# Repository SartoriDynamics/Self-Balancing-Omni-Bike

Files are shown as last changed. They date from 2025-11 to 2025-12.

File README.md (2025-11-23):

# Self-Balancing Omni Bicycle

UFMG BIAO-Kit is placed under the MIT License  
Copyright (c) 2024 by GTI (UFMG)

Hardware:
* ESP-WROOM-32 30 pin development board
* 2 Nidec 24-H
* 2 Set Tire wheel 88516 + 88517
* 1 2GT-280 belt, width 6mm
* 1 Module GY-521 MPU-6050
* 1 Power Bank Box Charger, DC 12V output, 3x18650 batteries

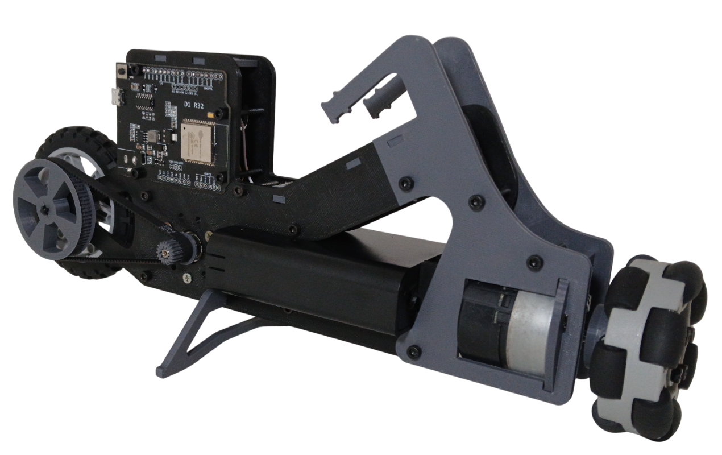
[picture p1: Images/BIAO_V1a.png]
BIAO

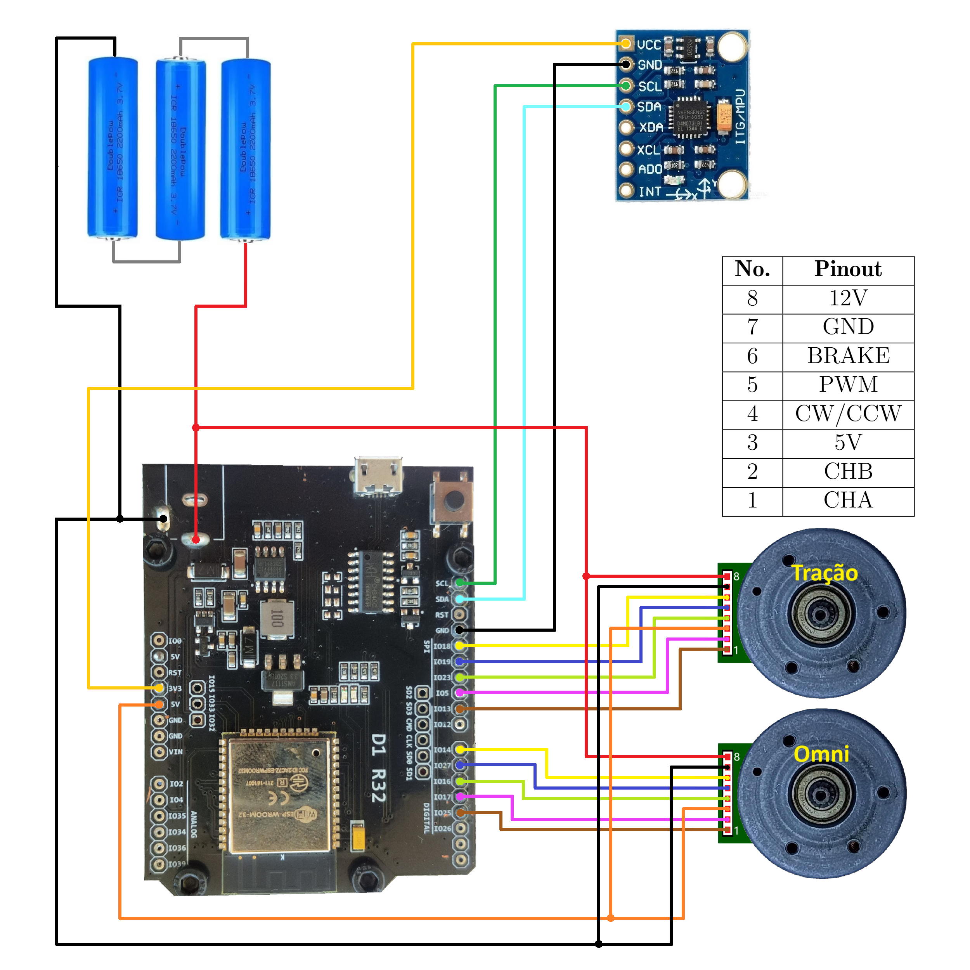
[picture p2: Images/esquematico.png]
esquematico


[Demonstration video](https://www.youtube.com/watch?v=WBLHfCbsgjU)

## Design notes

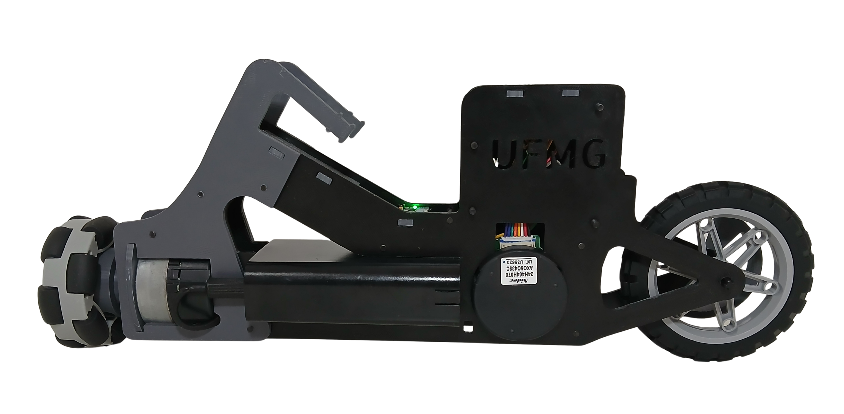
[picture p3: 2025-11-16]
Images/BIAO_V1b.png

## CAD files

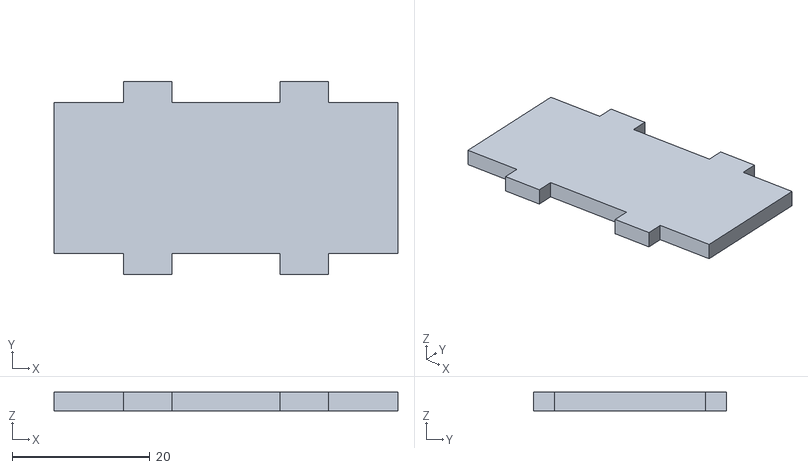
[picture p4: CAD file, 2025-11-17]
3D printing/Files/back_cover.stl
50.0 x 28.0 x 2.70

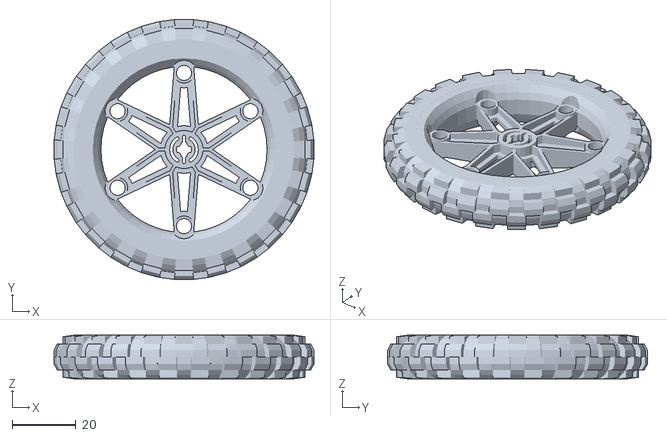
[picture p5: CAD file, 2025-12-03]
3D printing/Files/Extra/wheel.stl
81.5 x 81.5 x 13.7

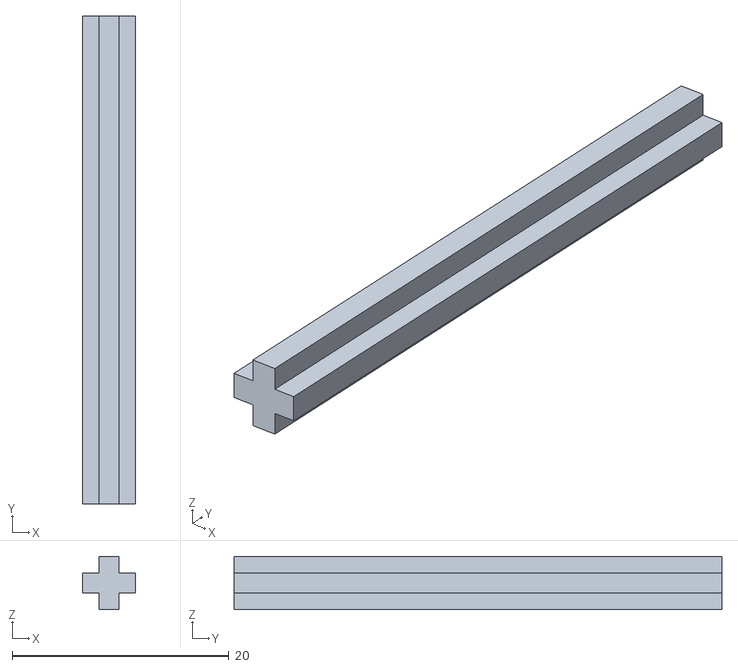
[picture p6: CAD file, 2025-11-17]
3D printing/Files/Extra/wheel_axle.stl
4.90 x 45.0 x 4.90

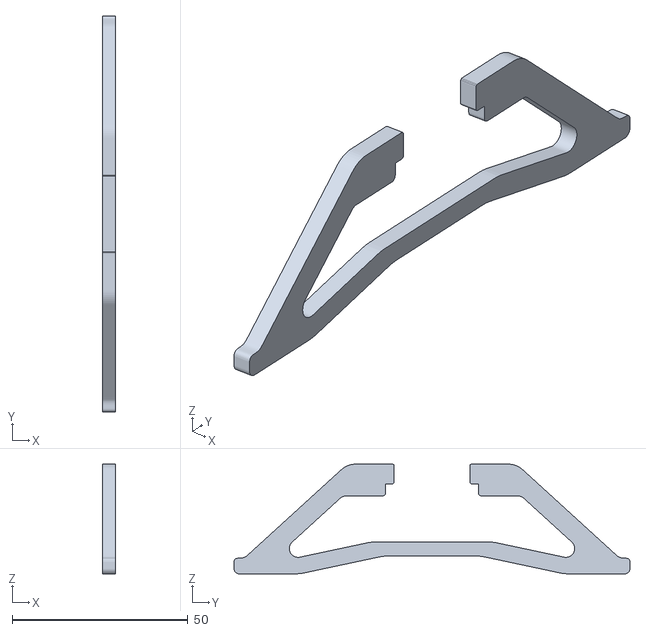
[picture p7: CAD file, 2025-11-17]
3D printing/Files/support.stl
3.60 x 112.7 x 31.2

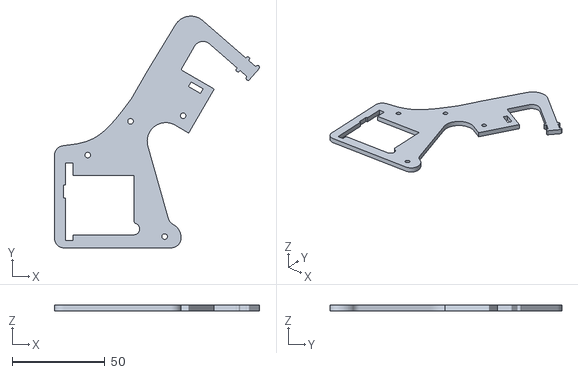
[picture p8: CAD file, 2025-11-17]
3D printing/Files/left_fork.stl
110.8 x 125.2 x 3.00

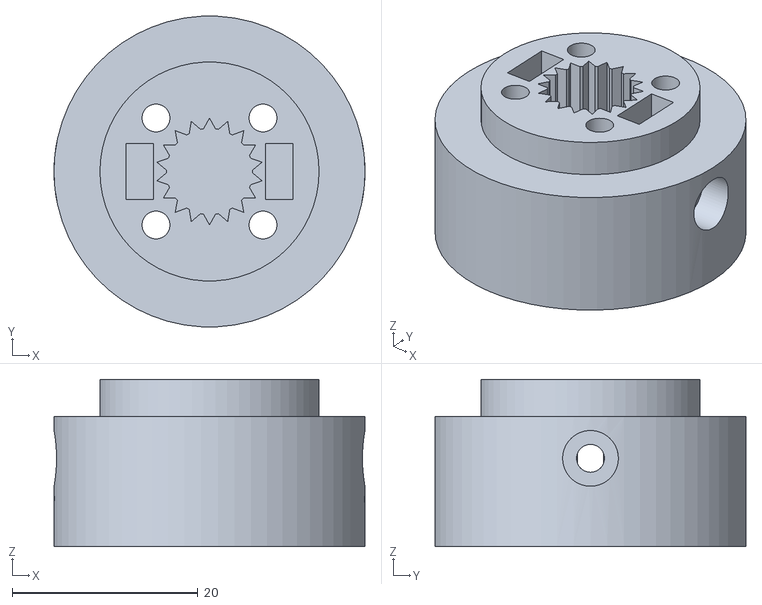
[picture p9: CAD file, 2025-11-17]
3D printing/Files/Omni_holder.stl
33.5 x 33.5 x 18.0

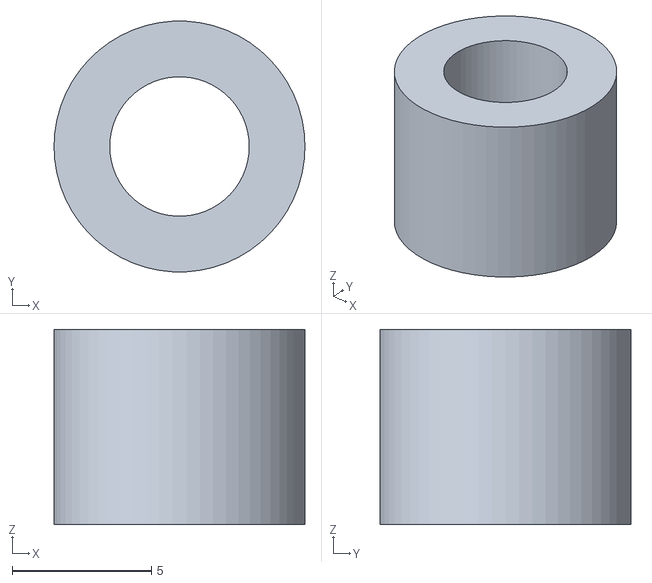
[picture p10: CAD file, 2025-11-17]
3D printing/Files/wheel_spacer.stl
9.00 x 8.99 x 7.00

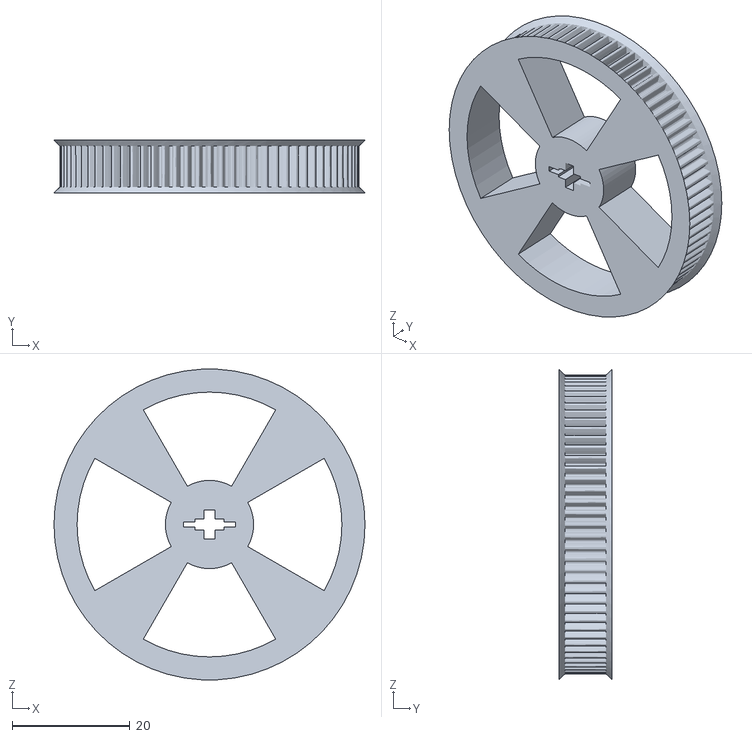
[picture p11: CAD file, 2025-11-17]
3D printing/Files/wheel_gear.stl
52.9 x 9.00 x 52.8

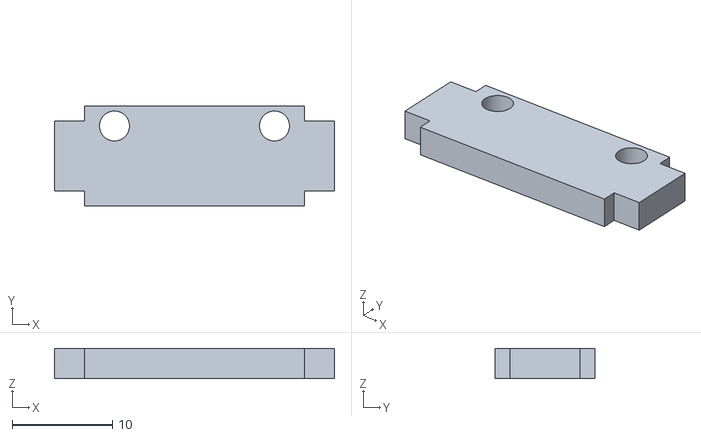
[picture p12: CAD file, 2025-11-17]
3D printing/Files/IMU_holder.stl
28.0 x 10.0 x 3.00

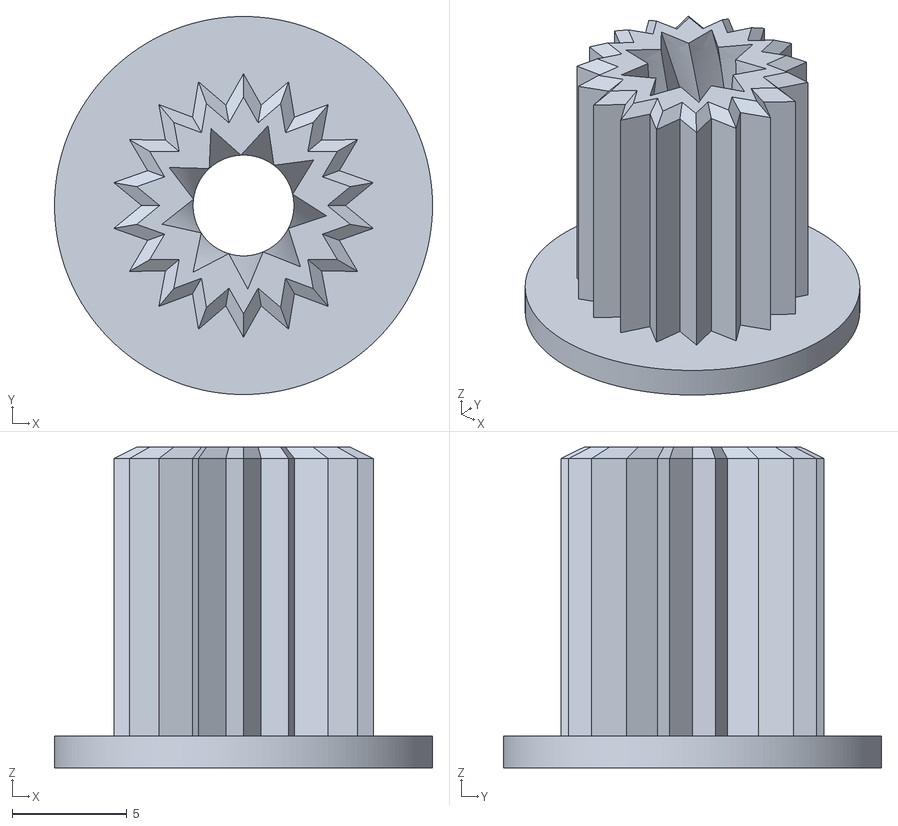
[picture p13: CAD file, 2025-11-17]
3D printing/Files/Nidec_gear.stl
16.5 x 16.5 x 14.0

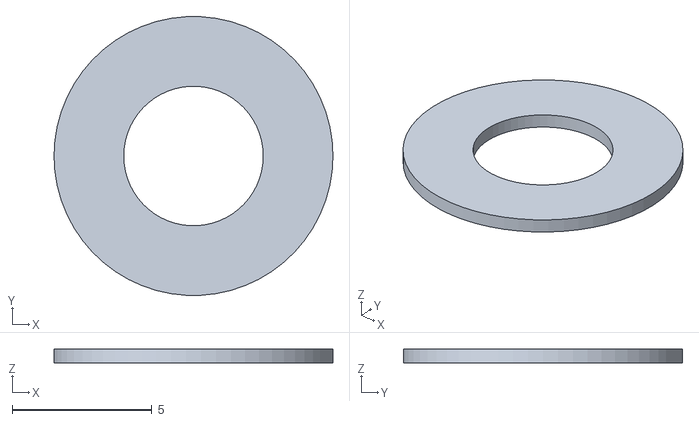
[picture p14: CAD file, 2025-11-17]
3D printing/Files/gear_spacer.stl
10.0 x 9.99 x 0.5

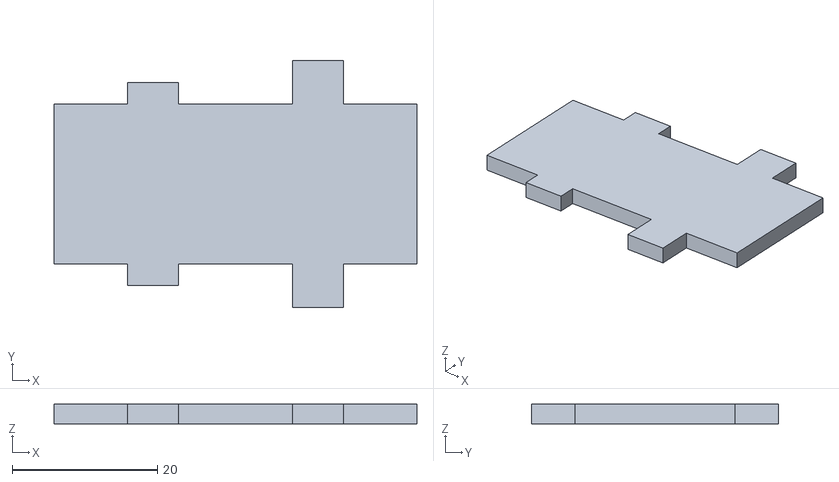
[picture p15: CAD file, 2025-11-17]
3D printing/Files/front_cover.stl
50.0 x 34.0 x 2.70

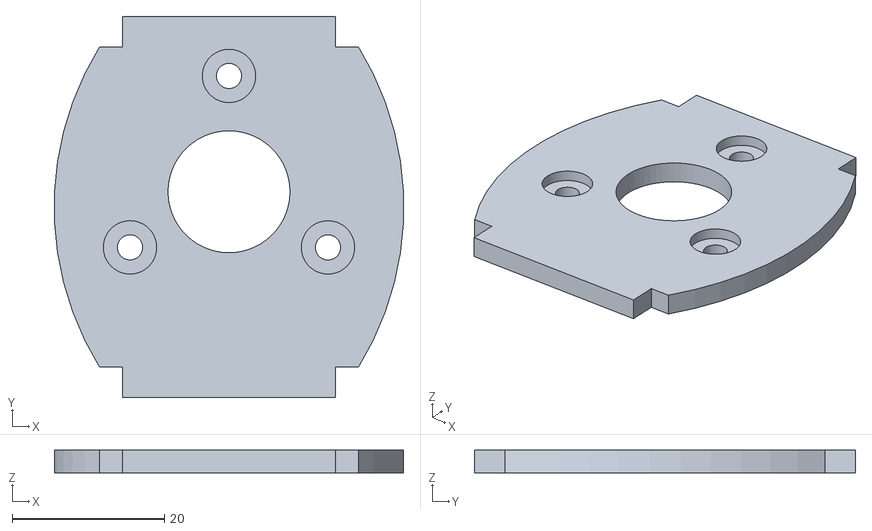
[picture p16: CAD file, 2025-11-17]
3D printing/Files/Nidec_holder.stl
45.8 x 50.0 x 3.00

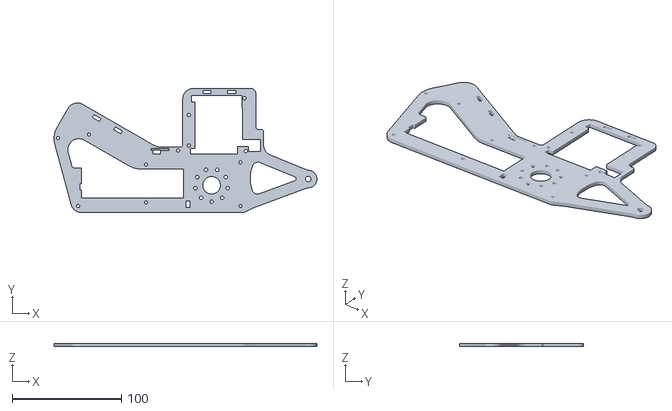
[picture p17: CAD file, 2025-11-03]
3D printing/Files/right_body.stl
240.4 x 113.6 x 3.00

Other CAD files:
3D printing/Files/right_fork.stl
3D printing/Files/left_body.stl

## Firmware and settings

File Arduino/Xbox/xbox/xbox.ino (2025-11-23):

// I2C libray communication
#include <Wire.h>

// ENCODER library based on the built in counter hardware
#include <ESP32Encoder.h>

// ESP32 BLUE LED pin
#define INTERNAL_LED 2

// IMU I2C address
#define MPU   0x68

// NIDEC PWM config
#define NIDEC_TIMER_BIT   8
#define NIDEC_BASE_FREQ   20000

// NIDEC pins: Reaction Wheel Motor
#define BRAKE1            14 //Yellow wire (Start/Stop)
#define NIDEC1_PWM        27 //Write wire  (PWM)
#define DIR1              16 //Green wire  (Forward/Reverse) 
#define ENCA_1            17 //Brown wire  (Signal A)  
#define ENCB_1            25 //Orange      (Signal B)  
#define NIDEC1_PWM_CH      1

// NIDEC pins: Traction Wheel Motor
#define BRAKE2           18 //Yellow wire (Start/Stop)
#define NIDEC2_PWM       19 //Write wire  (PWM)
#define DIR2             23 //Green wire  (Forward/Reverse) 
#define ENCA_2           5  //Brown wire // purple (Signal A)
#define ENCB_2           13 //Orange   (Signal B)
#define NIDEC2_PWM_CH     0

// Encoder vars
ESP32Encoder NIDEC1_ENC;
ESP32Encoder NIDEC2_ENC;

// Xbox controller conection
#include <XboxSeriesXControllerESP32_asukiaaa.hpp>
XboxSeriesXControllerESP32_asukiaaa::Core xboxController;
XboxSeriesXHIDReportBuilder_asukiaaa::ReportBase repo;

// Kalman Filter vars
float Q_angle = 0.001; // Angular data confidence
float Q_bias  = 0.005; // Angular velocity data confidence
float R_meas  = 1.0;
float roll_angle = 0.0;
float bias = 0.0;
float P[2][2] = {{ 1, 0 }, { 0, 1 }};
float K[2] = {0, 0};

// Control vars
//         theta        dthehta           psi              dpsi
float   K1 = -70,      K2 = -4.5,         K3 = -3,         K4 = -3;
float U = 0;
int pwm = 0;
float theta = 0, theta_dot = 0;            // System states
float psi = 0, psi_dot = 0;
float Ts = 0.01, currentT = 0.0, previousT = 0.0;        // Elapsed time in loop() function
float Txbox = 0.5, currentX = 0.0, previousX = 0.0;
float pulse2rad = 2*3.1415/3630;
bool start = true;

// Xbox vars
float traction = 0;
float psidot_ref = 0;
int marcha = 2;
bool reset = false;
bool manobra = false;

// MAIN SETUP
void setup() { // put your setup code here, to run once:
  Wire.begin();
  Serial.begin(115200);                   // make sure your Serial Monitor is also set at this baud rate.

  NIDECsetup();
  IMUsetup();

  pinMode(INTERNAL_LED,OUTPUT);
  digitalWrite(INTERNAL_LED,HIGH);  // Turn on blue led
  delay(1500);                      // Wait for the system to stabilize
  for (int i=1; i<= 400; i++){      // Wait for the Kalman filter stabilize
    IMUread();
    delay(5);
  }
  currentT = millis();
  digitalWrite(INTERNAL_LED,LOW); 

  xboxController.begin();
}

// MAIN LOOP
void loop() {// put your main code here, to run repeatedly:
  balance();
  xbox();
}

void balance() {// put your main code here, to run repeatedly:

  currentT = millis();
  if ((currentT - previousT)/1000.0 >= Ts) {
    previousT = currentT;
    
    IMUread();

    if (abs(roll_angle) < 2) start = true;

    if (abs(roll_angle) < 20 && start && !reset){
      digitalWrite(BRAKE1, HIGH);
      digitalWrite(BRAKE2, HIGH);

      theta += theta_dot * Ts;
      psi_dot = NIDEC1_ENC.getCount()*pulse2rad/Ts - psidot_ref;
      psi += psi_dot*Ts;
           
      U = K1*theta + K2*theta_dot + K3*psi + K4*psi_dot;
      pwm = U*21.3;
      if (NIDEC1_ENC.getCount() == 0) pwm += random(20)-10; // sometimes the motor stops
      MOTOR1cmd(-pwm);
      MOTOR2cmd(traction);

      NIDEC1_ENC.clearCount();       

    } else if (start) {
      digitalWrite(BRAKE1, LOW); // stop reaction wheel
      digitalWrite(BRAKE2, LOW); // stop traction wheel
      digitalWrite(INTERNAL_LED,HIGH);
      delay(5000);       // time to lift the bike
      digitalWrite(INTERNAL_LED,LOW);
      for (int i=1; i<= 400; i++){ //Wait for the Kalman Filter stabilize
        IMUread();
        delay(5);
      }
      previousT = millis();
      theta = 0.0;
      psi = 0.0;
      start = false;
      reset = false;
      NIDEC1_ENC.clearCount();
    }
  }   

}

void xbox() {
  currentX = millis();
  if ((currentX - previousX)/1000.0 >= Txbox) {
    previousX = currentX;
    
    xboxController.onLoop();

    if (xboxController.isWaitingForFirstNotification()) {
    } else {
      uint16_t joystickMax = XboxControllerNotificationParser::maxJoy;
      psidot_ref = ((float)xboxController.xboxNotif.joyRHori - 32768)/10000;
      traction = ((float)xboxController.xboxNotif.joyLVert - 32768)/((5-marcha)*70 + 128);

      marcha = xboxController.xboxNotif.btnRB && xboxController.xboxNotif.btnLB? 5 : marcha;
      marcha = xboxController.xboxNotif.btnX ? 3 : marcha;
      marcha = xboxController.xboxNotif.btnA ? 2 : marcha;
      marcha = xboxController.xboxNotif.btnB ? 1 : marcha;

      manobra = xboxController.xboxNotif.btnRS? true : manobra;
      manobra = xboxController.xboxNotif.btnLS? false : manobra;

      if (manobra){
        psidot_ref = 32768/10000;
        traction = 32768/((5-marcha)*70 + 128);
      }

      reset = xboxController.xboxNotif.btnStart? true : reset;      
    }

    if (pwm > 180) {
      xboxVibrationRight(pwm-180);
    } else if(pwm < -180) {
      xboxVibrationLeft(pwm+180);
    }

  }   
}

void xboxVibrationRight(float intensidade) {
  repo.v.select.center = false;
  repo.v.select.left = false;
  repo.v.select.right = true;
  repo.v.select.shake = false;
  repo.v.power.right = intensidade;
  repo.v.timeActive = Txbox*100;
  xboxController.writeHIDReport(repo);
}

void xboxVibrationLeft(float intensidade) {
  repo.v.select.center = false;
  repo.v.select.left = true;
  repo.v.select.right = false;
  repo.v.select.shake = false;
  repo.v.power.left = intensidade;
  repo.v.timeActive = Txbox*100;
  xboxController.writeHIDReport(repo);
}


// SETUP functions
void IMUsetup(){
  // Initialize the MPU6050
  Wire.beginTransmission(MPU);           //begin, Send the slave adress (in this case 68)              
  Wire.write(0x6B);                      //make the reset (place a 0 into the 6B register)
  Wire.write(0);
  Wire.endTransmission(true);            //end the transmission
  //Gyro config
  Wire.beginTransmission(MPU);           //begin, Send the slave adress (in this case 68) 
  Wire.write(0x1B);                      //We want to write to the GYRO_CONFIG register (1B hex)
  // Wire.write(0x00000000);
  Wire.endTransmission();                //End the transmission with the gyro
  //Acc config
  Wire.beginTransmission(MPU);           //Start communication with the address found during search.
  Wire.write(0x1C);                      //We want to write to the ACCEL_CONFIG register
  Wire.write(0b00000000);                //Set the register bits as 00000000 (+/- 2g full scale range), 00010000 (+/- 8g full scale range)
  Wire.endTransmission(); 
}

void NIDECsetup(){
  pinMode(BRAKE1, OUTPUT);
  digitalWrite(BRAKE1, HIGH);

  pinMode(BRAKE2, OUTPUT);
  digitalWrite(BRAKE2, HIGH);
  
  pinMode(DIR1, OUTPUT);
  ledcSetup(NIDEC1_PWM_CH, NIDEC_BASE_FREQ, NIDEC_TIMER_BIT);
  ledcAttachPin(NIDEC1_PWM, NIDEC1_PWM_CH);
  MOTOR1cmd(0);
  
  pinMode(DIR2, OUTPUT);
  ledcSetup(NIDEC2_PWM_CH, NIDEC_BASE_FREQ, NIDEC_TIMER_BIT);
  ledcAttachPin(NIDEC2_PWM, NIDEC2_PWM_CH);
  MOTOR2cmd(0);

  // Encoders setup:
  ESP32Encoder::useInternalWeakPullResistors = puType::up;
  // Encoder 1:
	NIDEC1_ENC.attachFullQuad(ENCB_1, ENCA_1);
  NIDEC1_ENC.clearCount();
  // Encoder 2:
	NIDEC2_ENC.attachFullQuad(ENCB_2, ENCA_2);
  NIDEC2_ENC.clearCount();
}

// IMU function: Kalman Filter
void IMUread(){
  // read IMU
  int16_t ax,ay,az,temp,gx,gy,gz;
  Wire.beginTransmission(MPU);    // IMU address: 0x68
  Wire.write(0x3B);  
  Wire.endTransmission(false);
  Wire.requestFrom(MPU,14);        // IMU address: 0x68
  ax=Wire.read()<<8|Wire.read();   // X-axis value: 16384.0; 
  ay=Wire.read()<<8|Wire.read();   // Y-axis value: 16384.0;     
  az=Wire.read()<<8|Wire.read();   // Z-axis value: 16384.0;  
  temp=Wire.read()<<8|Wire.read();      
  gx=Wire.read()<<8|Wire.read();  
  gy=Wire.read()<<8|Wire.read();  
  gz=Wire.read()<<8|Wire.read();  
  //accelerometer angles in degrees (or rads)
  float ax_angle = atan2(ay, sqrt(ax*ax + az*az)) * 57.3; // roll
  //float ay_angle = atan2(ax, sqrt(ay*ay + az*az)) * 57.3; // pitch
  // float az_angle = atan2(sqrt(ax*ax + az*az), az) * 57.3; // yaw (useless)
  // gyro measurements in degress (or rads)
  gx =  gx / 131; //* 0.0174533; // Datasheet Sensitivity Scale Factor: 131, 65.5, 32.8, 16.4 for degrees/sec and Scale pi/180 = 0.0174533 for rad/sec
  // gy =  gy / 65.5; //* 0.0174533; // Datasheet Sensitivity Scale Factor: 131, 65.5, 32.8, 16.4 for degrees/sec and Scale pi/180 = 0.0174533 for rad/sec
  // gz =  gz / 65.5; //* 0.0174533; // Datasheet Sensitivity Scale Factor: 131, 65.5, 32.8, 16.4 for degrees/sec and Scale pi/180 = 0.0174533 for rad/sec
  
  
  // begin: Kalman filter - Roll Axis (X)
  roll_angle += (gx - bias) * Ts;
  
  P[0][0] += (Q_angle - P[0][1] - P[1][0]) * Ts;
  P[0][1] += -P[1][1] * Ts;
  P[1][0] += -P[1][1] * Ts;
  P[1][1] += Q_bias * Ts;
  //
  K[0] = P[0][0] / (P[0][0] + R_meas);
  K[1] = P[1][0] / (P[0][0] + R_meas);  
  //
  roll_angle += K[0] * (ax_angle - roll_angle); 
  bias       += K[1] * (ax_angle - roll_angle);
  //
  float P00_temp = P[0][0];
  float P01_temp = P[0][1];

  P[0][0] -= K[0] * P00_temp;
  P[0][1] -= K[0] * P01_temp;
  P[1][0] -= K[1] * P00_temp;
  P[1][1] -= K[1] * P01_temp;
  // end: Kalman filter 

  theta_dot = (gx - bias)/57.3; // Unbiased gyro speed
  
  // //  Complementary filter   
  // roll_anglec = 0.98 * (roll_anglec + gx * Ts) + 0.02 * ax_angle;
  // pitch_anglec = 0.98 * (pitch_anglec + gy * Ts) + 0.02 * ay_angle;
  // yaw_anglec = 0.98 * (yaw_anglec + gz * Ts) + 0.02 * az_angle;

}  

// NIDEC functions
void MOTOR1cmd(int sp) {
  if (sp < 0) {
    digitalWrite(DIR1, HIGH);
    sp = -sp;
  } else {
    digitalWrite(DIR1, LOW);
  }
  ledcWrite(NIDEC1_PWM_CH, int(sp > 255 ? 0 : 255 - sp));
}

void MOTOR2cmd(int sp) {
  if (sp < 0) {
    digitalWrite(DIR2, HIGH);
    sp = -sp;
  } else {
    digitalWrite(DIR2, LOW);
  }
  ledcWrite(NIDEC2_PWM_CH, int(sp > 255 ? 0 : 255 - sp));
}

/* XBOX controller buttons:
  bool btnA, btnB, btnX, btnY;
  bool btnShare, btnStart, btnSelect, btnXbox;
  bool btnLB, btnRB;
  bool btnLS, btnRS;
  bool btnDirUp, btnDirLeft, btnDirRight, btnDirDown;
  uint16_t joyLHori = maxJoy / 2;
  uint16_t joyLVert = maxJoy / 2;
  uint16_t joyRHori = maxJoy / 2;
  uint16_t joyRVert = maxJoy / 2;
  uint16_t trigLT, trigRT;
*/

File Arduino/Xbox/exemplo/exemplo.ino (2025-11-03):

#include <XboxSeriesXControllerESP32_asukiaaa.hpp>

// Required to replace with your xbox address
// XboxSeriesXControllerESP32_asukiaaa::Core
// xboxController("44:16:22:5e:b2:d4");

// any xbox controller
XboxSeriesXControllerESP32_asukiaaa::Core xboxController;

void setup() {
  Serial.begin(115200);
  Serial.println("Starting NimBLE Client");
  xboxController.begin();
}

void demoVibration() {
  XboxSeriesXHIDReportBuilder_asukiaaa::ReportBase repo;
  Serial.println("full power for 1 sec");
  xboxController.writeHIDReport(repo);
  delay(2000);

  repo.v.select.center = true;
  repo.v.select.left = false;
  repo.v.select.right = false;
  repo.v.select.shake = false;
  repo.v.power.center = 30;  // 30% power
  repo.v.timeActive = 50;    // 0.5 second
  Serial.println("run center 30\% power in half second");
  xboxController.writeHIDReport(repo);
  delay(2000);

  repo.v.select.center = false;
  repo.v.select.left = true;
  repo.v.power.left = 30;
  Serial.println("run left 30\% power in half second");
  xboxController.writeHIDReport(repo);
  delay(2000);

  repo.v.select.left = false;
  repo.v.select.right = true;
  repo.v.power.right = 30;
  Serial.println("run right 30\% power in half second");
  xboxController.writeHIDReport(repo);
  delay(2000);

  repo.v.select.right = false;
  repo.v.select.shake = true;
  repo.v.power.shake = 30;
  Serial.println("run shake 30\% power in half second");
  xboxController.writeHIDReport(repo);
  delay(2000);

  repo.v.select.shake = false;
  repo.v.select.center = true;
  repo.v.power.center = 50;
  repo.v.timeActive = 20;
  repo.v.timeSilent = 20;
  repo.v.countRepeat = 2;
  Serial.println("run center 50\% power in 0.2 sec 3 times");
  xboxController.writeHIDReport(repo);
  delay(2000);
}

void loop() {
  xboxController.onLoop();
  if (xboxController.isConnected()) {
    if (xboxController.isWaitingForFirstNotification()) {
      Serial.println("waiting for first notification");
    } else {
      demoVibration();
    }
  } else {
    Serial.println("not connected");
    if (xboxController.getCountFailedConnection() > 2) {
      ESP.restart();
    }
  }
  Serial.println("at " + String(millis()));
  delay(500);
}

/* XBOX controller buttons:
  bool btnA, btnB, btnX, btnY;
  bool btnShare, btnStart, btnSelect, btnXbox;
  bool btnLB, btnRB;
  bool btnLS, btnRS;
  bool btnDirUp, btnDirLeft, btnDirRight, btnDirDown;
  uint16_t joyLHori = maxJoy / 2;
  uint16_t joyLVert = maxJoy / 2;
  uint16_t joyRHori = maxJoy / 2;
  uint16_t joyRVert = maxJoy / 2;
  uint16_t trigLT, trigRT;
*/

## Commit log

2025-11-03 add arduino files
2025-11-14 Name changed
    [corpo-direito.stl, corpo-esquerdo.stl]
2025-11-17 3D printing
    [DrilledAxis.stl, corpo-esquerdo - corpo-esquerdo.stl, eixo traseiro.stl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]
2025-11-23 files changed
    [corpo-esquerdo.stl]
2025-12-03 Name changes
    [borracha-roda.stl, eixo-traseiro.stl, engrenagem-nidec.stl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]
